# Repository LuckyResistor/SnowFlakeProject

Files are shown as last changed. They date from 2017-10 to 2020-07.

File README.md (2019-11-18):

# The Snowflake Decoration Project

This repository contains all hardware and software sources for the snowflake decoration project.
You will also find a number of documentation pages with the wiring or arrangement of the LEDs.

## More Information

Find more information about the project here:
[Snowflake Decoration Project](https://luckyresistor.me/projects/snow-flake-decoration/)

## License

All files are licensed under the GNU General Public License v3.0.

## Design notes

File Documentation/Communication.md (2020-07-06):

# Communication Protocol
## Summary
This document explains the details about the communication protocol and the idea behind this protocol as implemented in the firmware.

## Background and Idea
Each snow flake board has a data input and output pad to allow communication between multiple boards. The idea is that multiple snow flakes are chained to a single strand. On this strand, the snow flake boards use a communication protocol to synchronise the displayed effect.

1. A communication will make sure all snow flakes will display the same scene on the same strand. If all snow flakes display different scenes, it will look chaotic.
2. Because the internal oscillator of the MCU is used, not all snow flakes will display the scenes in exactly the same speed. A synchronisation signal will make sure there is no "shift" over time and all snow flakes will blend the scenes at the same time.
3. In an initial negotiation, each snow flake can find out the own position in the strand. This position can be used to create scenes which use all snow flakes in the same strand as one huge canvas. An effect could start at the first snow flake and run over all snow flakes in a smooth sequence.
4. Theoretically, the communication can also be used to detect how many snow flake boards are part of the same strand. This final number can be reported back the whole strand. It would keep the firmware flexible, boards can be added and removed from a strand and the scenes would always work with the current number of snow flakes. While this is possible, it is not part of the current firmware implementation. This firmware always assumes a fixed number of snow flakes, which is configured in the firmware as a configuration variable.

## Basic Principle
The communication is a primary/secondary system, where the first snow flake in the strand is the primary. The primary sends data down the strand which is received by the secondarys. Each secondary just passes the received data unmodified to the next secondary in the strand.

For robustness, the protocol uses a pulse length encoding. Different lengths of pulses encode bits and control information. Because of the variations in the CPU frequencies and unshielded cables, there is a certain timing tolerance built in the protocol.

## Negotiation
In the start process of each snow flake, the position and mode of the element is determined. First, the system checks if it is the first element in the strand:

1. The output line is set to high.
2. The system waits a short time if the input line goes to high.
3. In the case the input line goes to high, the system switches to secondary mode.
4. In the case the input line stays low, the system switches to primary mode.
5. The output line is set to low.

### Negotiation as Primary
The primary system assigns index zero to itself and sends the next index number (1) to the next secondary in the strand.

### Negotiation as Secondary
The secondary waits for an incoming number from the previous element in the strand. After it receives this number, it assigns this number to itself as index number and sends this number plus one to the next secondary in the strand.

### Index numbers
The index number is sent with the same protocol described below. The index number is encoded like this:

`0x1B7200XX` Where XX is the index number and all other digits in this number are used as "magic" to make sure this is a valid number.

### Error Handling
There are a number of error situations in the negotiation:

1. No number is received in a certain time frame, the negotiation times out.
2. The received number has the wrong format.

In this error cases, the snow flake will flag the error internally. The firmware will display a special scene to indicate the error to the user.

## Regular Communication
The regular communication consist of 32bit values sent from the primary to all secondarys. Currently there is a single command implemented:

Blend scene: `0xA514YYXX` - XX is the new scene number, YY the entropy value for the new scene.

This command is sent before all snow flakes shall blend to a new scene. A synchronisation signal is sent after this command, which will trigger the actual blend of the scene.

## Protocol
The protocol is using a simple pulse length encoding to transfer data. A pulse is pulling the data line to high and back to low. The time while the line was held high determines the meaning of this information element.

A timer is used to measure the incoming pules. Another timer is used to generate the outgoing pules. Both timer use the same clock source and divider to create the best possible precision.

- Length `0x0200`: Zero Bit
- Length `0x0400`: One Bit
- Length `0x0600`: Break Signal
- Length `0x0800`: Synchronisation Signal

For each transmission, a single 32bit value is sent. The lowest bit is sent first. A transmission consist of 32 zero or one bit signals, followed by a break signal.

A synchronisation signal can theoretically be sent at any time, but usually should be sent between value transmissions.

## Error handling

### Technical Problems
 
There are a number of technical situations how the transmission of signals and values can fail:

1. A signal with an unknown length is received.
2. A break signal is received, but the number of previously received zero and one bits is not 32.

In both cases, the communication is reset and the secondary is waiting for a new value. Any further handling of these problems make no sense, because there is no way to recover from them.

### Logical Problems

There are a number of logical problems which can occur. This logic problems are not handled by the firmware.

1. _There is inference in the transmission and wrong values are received._ For this case, a checksum would have to be added to the protocol. Also either a feedback channel would have to exist to report the problem and trigger resending the data - or the protocol would have to repeat each value a number of times to allow error correction.
2. _No data is received._ To catch this case, the firmware would have to run a kind of watch-dog timer. If no value is received in a given time, the board would have to signal this problem.

It makes no much sense to handle this logical problems. Most likely the reason is a hardware problem. The situation will be visible, because the strand will not synchronise the scenes or the elements will not start at all.

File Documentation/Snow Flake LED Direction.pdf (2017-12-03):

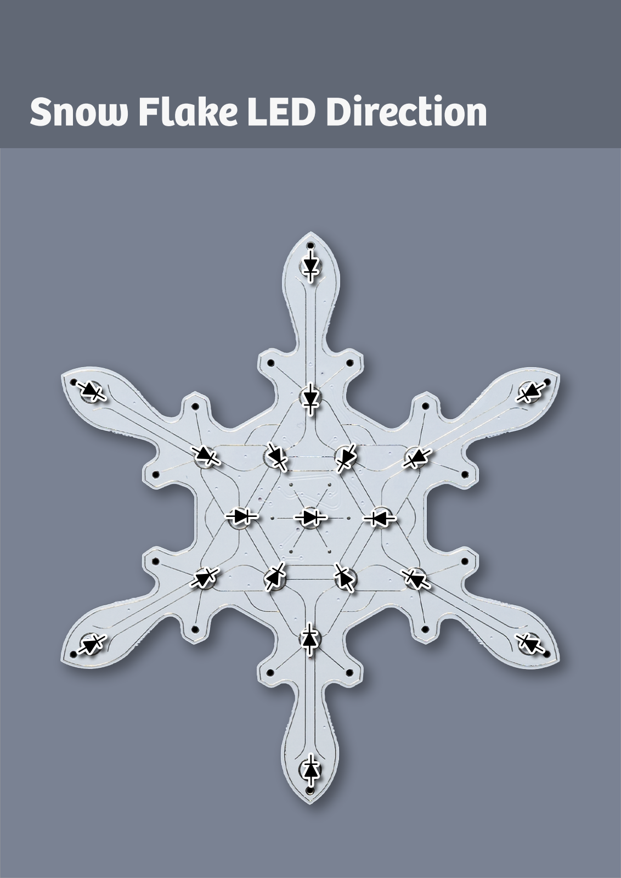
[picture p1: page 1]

Snow Flake LED Direction

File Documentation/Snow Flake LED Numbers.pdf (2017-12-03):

# Snow Flake LED Numbers

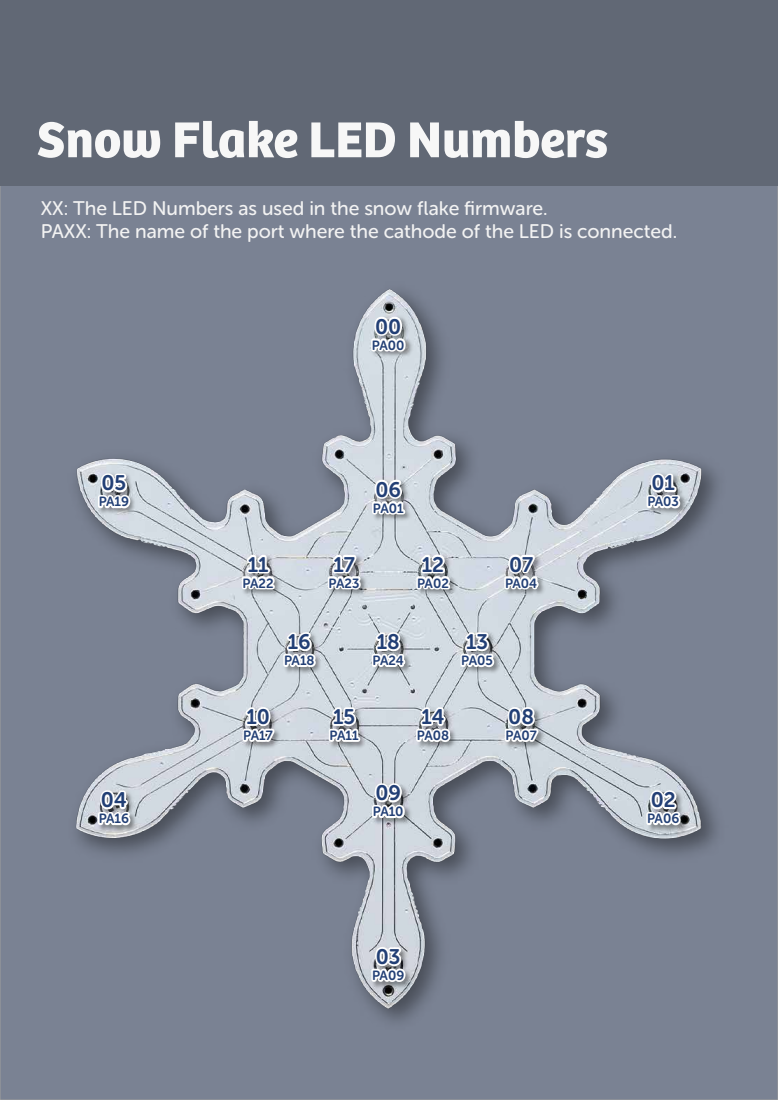
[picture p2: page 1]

XX: The LED Numbers as used in the snow flake firmware.
PAXX: The name of the port where the cathode of the LED is connected.

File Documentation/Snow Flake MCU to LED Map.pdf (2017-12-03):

# Snow Flake MCU to LED Map

This map shows which LED is connected to which pin on the MCU. The cathode of each LED is connected to the pin of the MCU, to test the LED connect the pin of the MCU to ground.

LEDX/RX is the reference from the electronic schema.
XX is the LED number as used in the firmware.
PAXX is the name/port of the MCU pin.

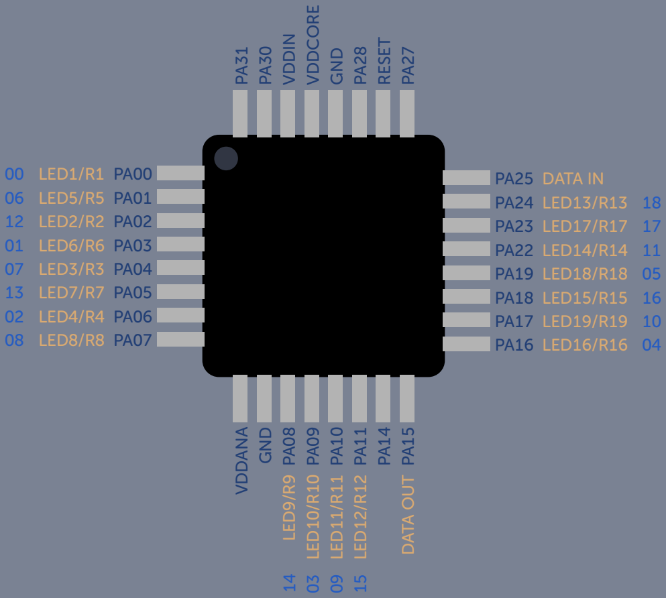
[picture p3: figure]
VDDANA; GND; VDDIN; VDDCORE; RESET; LED1/R1 LED5/R5 LED2/R2 LED6/R6 LED3/R3 LED7/R7 LED4/R4; LED8/R8; LED16/R16; LED19/R19; LED15/R15; LED18/R18; LED14/R14; LED17/R17; LED13/R13; DATA IN; LED9/R9; LED10/R10; LED11/R11; LED12/R12; DATA OUT

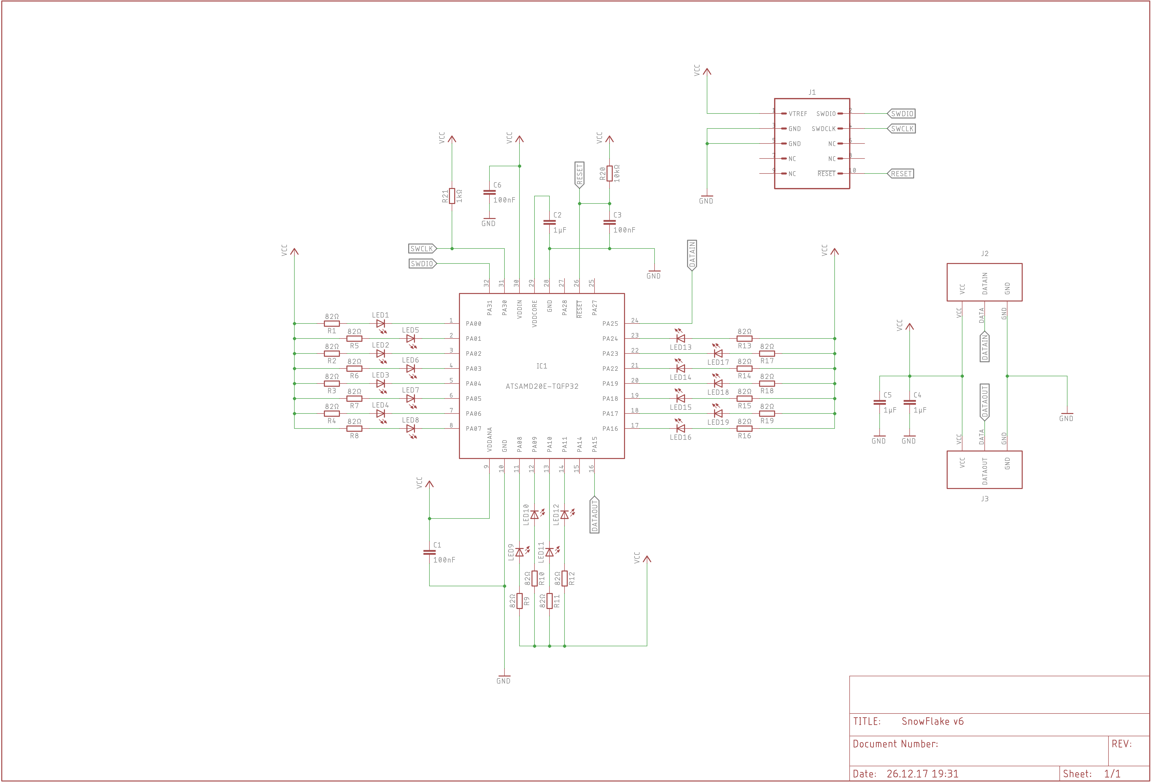
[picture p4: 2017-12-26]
Board/SnowFlake Schema.png

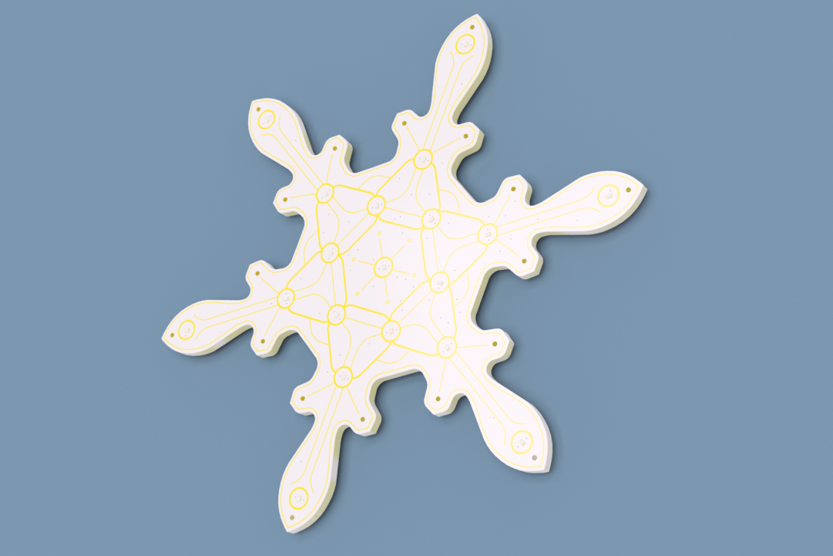
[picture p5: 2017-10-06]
Board/SnowFlake 3D Preview.png

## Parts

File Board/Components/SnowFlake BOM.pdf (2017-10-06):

### Snow Flake V5 BOM

Qty | Manufacturer | MPN | Schematic Reference | Description
1 | Harwin | M50-3600542R | J1 | 2x5 SMD Header for Programming
19 | Rohm | SCMP13WBC8W1 | LED1-19 | White 150mcd LED Package 0402
1 | Microchip | ATSAMD20E15A-AUT | IC1 | Atmel SAM D20E 32kb flash
19 | KOA Speer | RK73H2ATTD82R0F | R1-19 | 82Ω
1 | KOA Speer | RK73H2ATTDD1002F | R20 | 10kΩ
2 | Murata | GRM21BR60J106ME19L | C4,C5 | 10µF
3 | Murata | GRM21BR71H104JA01L | C1,C3,C6 | 0.1µF
1 | KOA Speer | RK73H2ATTDD1001F | R21 | 1kΩ
1 | Murata | GRM21BR71A105KA01L | C2 | 1µF

1

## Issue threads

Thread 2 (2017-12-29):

Pseudo random number generator is not seeded

LuckyResistor, 2017-12-29:
# Summary
The pseudo random number generator is not properly seeded at the start of the firmware. Therefore the master will cycle always through the exact same sequence of scenes.

# Background
It is not trivial to get good entropy from MCUs in a safe way. Just using the ADC to sample the voltage of a unconnected pin can work, but is not reliable. The Atmel SAM D20E can measure the internal temperature reference, which is hopefully a very noisy source. This would be worth a check.

# Implementation
All random numbers are generated using the methods in the `Helper` module. The original is the PRNG engine `gRandomGeneratorEngine` there. This engine has to be seeded with enough entropy from the hardware in the `initialize()` method. A call of the `seed()` function of the engine should be enough.

The hardware related methods to get the actual values have to be placed in the `Hardware` module so they can be accessed by the `Helper` module.

Closed 2017-12-30.

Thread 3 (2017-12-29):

Software Based Communication Too Unstable. Use Hardware Method Instead.

LuckyResistor, 2017-12-29:
# Summary
The current implementation to capture pulses from the data input is a very simple and fast implemented solution. It is not as reliable as it could be, which leads to communication problems, especially on long strands.

# Background
The PWM for the LEDs is done in software and requires a very precise interrupt. Every other interrupt requires to have a lower priority, otherwise e.g. the communication would lead to a visible flicker of the LEDs. This constraint makes it difficult to use interrupts for the communication in a precise way.

The original idea was to use a very slow pulse modulation to circumvent this issue. Mirroring the signal down the line turns out to be a problem. The small timing issues sum up and often the last elements in the strand can not interpret the pulses correctly.

# Possible Solutions
## Using Events and a Timer
The Atmel SAM D20E has a powerful event system. Sadly is is hard to understand and the documentation lacks examples. An event is nothing else as a configurable digital line inside of the MCU which can configured to connect some signal from a peripheral to the input of another peripheral.

Nevertheless it is possible to configure the external interrupt `EIC` to generate a event by configuring `CONFIGn` as `HIGH` level detector and let it generate a event. A timer can be connected to this signal. The timer can be configured in `PPW` mode to automatically capture the period and pulse-width from this signal. The interrupt to process the captured value can then be generated by the timer on capture instead of directly from the `EIC`.

## Serial Communication Using `SERCOM`
There is also the `SERCOM` system in the Atmel SAM D20E. When I designed the circuit I made sure the data in/out pins are also usable with the `SERCOM` module.

Configuring this module, it is possible to establish an asynchronous serial communication between the boards. The interrupt could be generated after receiving a single byte. If the BAUD rate is low enough, it should be no problem to capture every byte from the transmission in time.

This solution would require rewriting the communication from ground up to use a byte stream instead of fixed 32bit values. Also the synchronisation signal would be based on a sent byte and may not have the same precision as the simple signal currently used.

LuckyResistor, 2019-11-13:
The current implementation using a slow pulse width modulation captured via EIC has proven stable. Even on long strands, I observed no transmission errors.

Closed 2019-11-13.

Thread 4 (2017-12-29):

Scene Variations Depending on Strand Position

LuckyResistor, 2017-12-29:
# Summary
The main goal of the communication and strand position detection was to create scenes which play "over the whole strand". The current firmware lacks this kind of scenes and just synchronises the currently played scene to all other boards in the strand.

# Implementation
A board can access the current position of the own board and the number of boards in the strand. This will allow to e.g. shift an effect based on this information to play an animation over the whole strand.

One idea I have in mind is to run the sparkle effect in the `IceSparke` scene from top to bottom over all boards in sequence.

LuckyResistor, 2019-11-13:
Implemented in the Ice Sparke and Rain effect.

Closed 2019-11-13.

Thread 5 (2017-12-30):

If there is only one scene, the master still blends to the same one.

LuckyResistor, 2017-12-30:
# Summary
If there is only one scene defined, the master board still blends to the same scene. This can lead to glitches in the display of the scenes look very similar and do not use entropy.

# Solution
- Disable blending if only one scene is defined.
- Add a configuration option to enable blending on the same scene for entropy testing.

Closed 2017-12-30.

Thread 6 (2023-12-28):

Snowflakes turning off randomly

druck13, 2023-12-28:
After 3 or 4 years of working perfectly both of my sets of Pimoroni snowflakes have started turning themselves off after a period of anywhere from a few minutes to a couple of hours, sometimes just one set, but usually both sets within a few seconds of each others. They are powered from two different USB power supplies which work fine with Pi Zeros.

I looked at the configuration webpage to check I hadn't accidentally invoked some sort of auto switch off function using the button, but that doesn't seem to be the case.

Any ideas?

LuckyResistor, 2023-12-30:
Hello,

First of all, I apologize for my late response. I've encountered a similar issue with one decoration produced by Pimoroni, where some LEDs stayed on as if the microcontroller firmware suddenly stopped. In your case, do all the LEDs go black, or are some staying on?

From my experience, my own versions have been working flawlessly for several years. I don't believe this is a firmware issue; it seems more like a hardware problem. My guess, in order of likelihood, would be: a faulty capacitor, a faulty voltage regulator, hairline breaks in the flat band cables, oxidization on the connectors, or faulty solder joints. All of these could lead to lower voltage than expected, causing the microcontroller to stop.

If you have the necessary tools, I would be very interested in learning more. Could you please measure the voltage levels and check for any faulty capacitors? Also, I recommend raising this issue in the Pimoroni forums. It's probably the best place to get feedback from other users who may have encountered the same problem.

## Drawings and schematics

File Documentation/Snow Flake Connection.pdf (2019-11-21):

# Snow Flake Connection

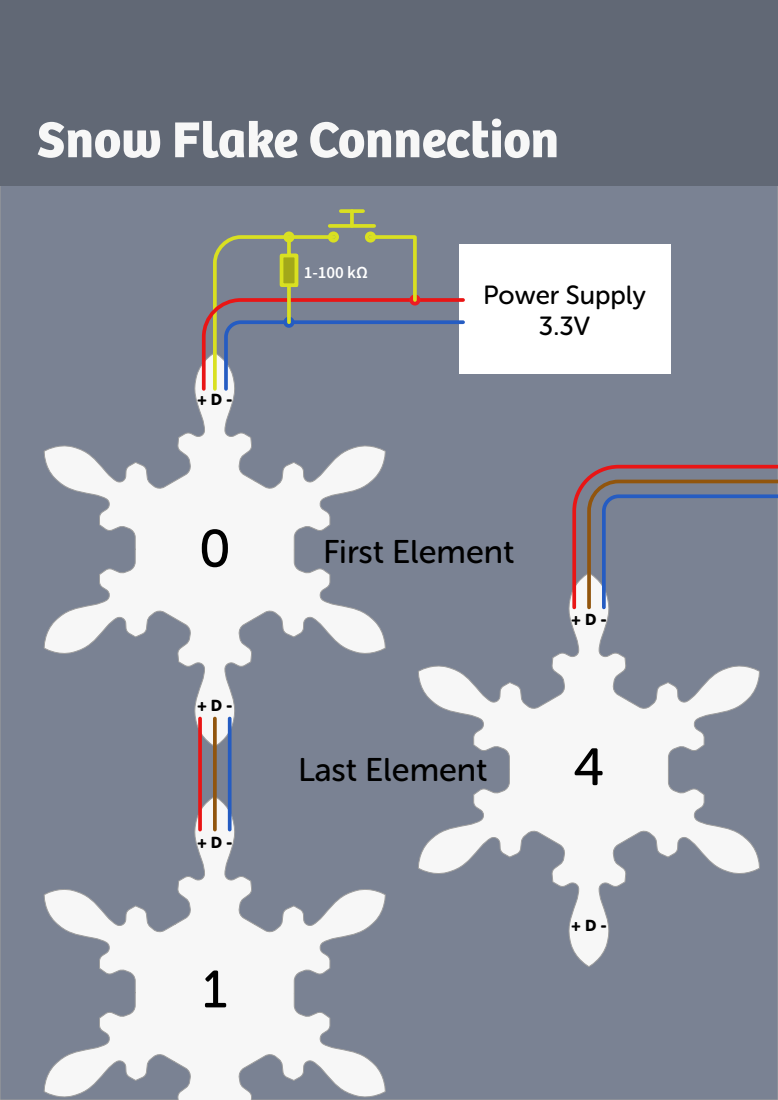
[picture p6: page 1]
Power Supply 3.3V; First Element; Last Element

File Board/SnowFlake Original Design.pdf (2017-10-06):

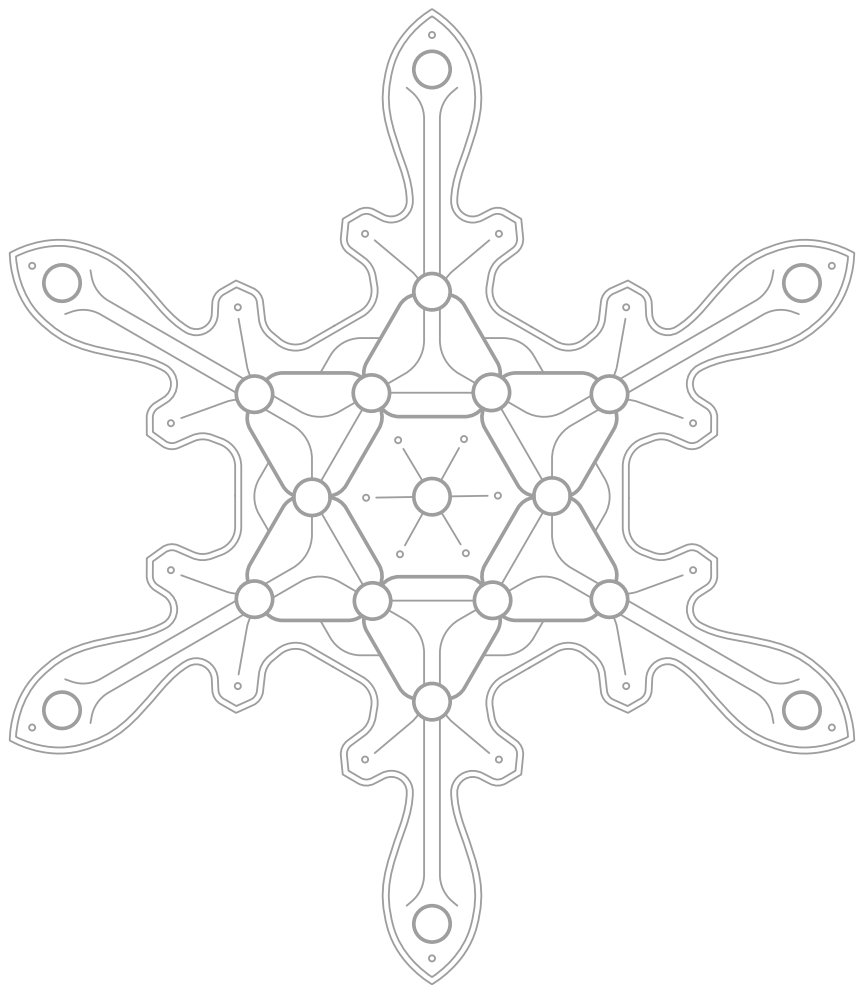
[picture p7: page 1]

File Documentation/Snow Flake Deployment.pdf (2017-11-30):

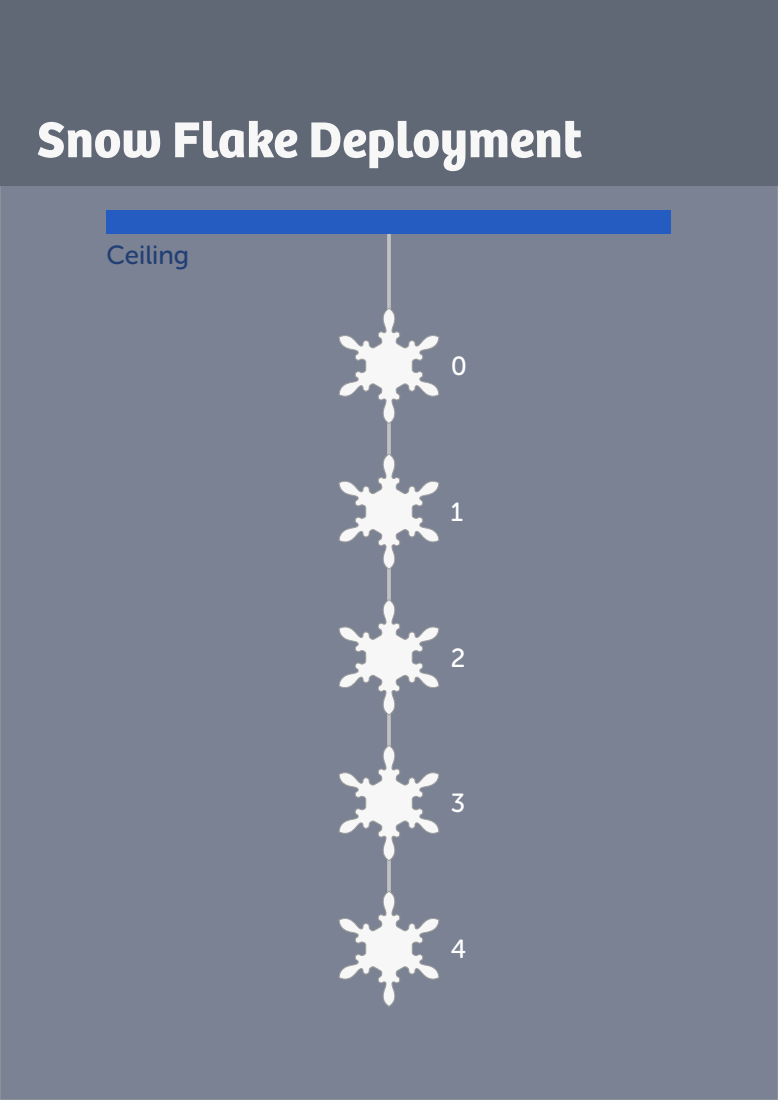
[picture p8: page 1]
Ceiling

Snow Flake Deployment

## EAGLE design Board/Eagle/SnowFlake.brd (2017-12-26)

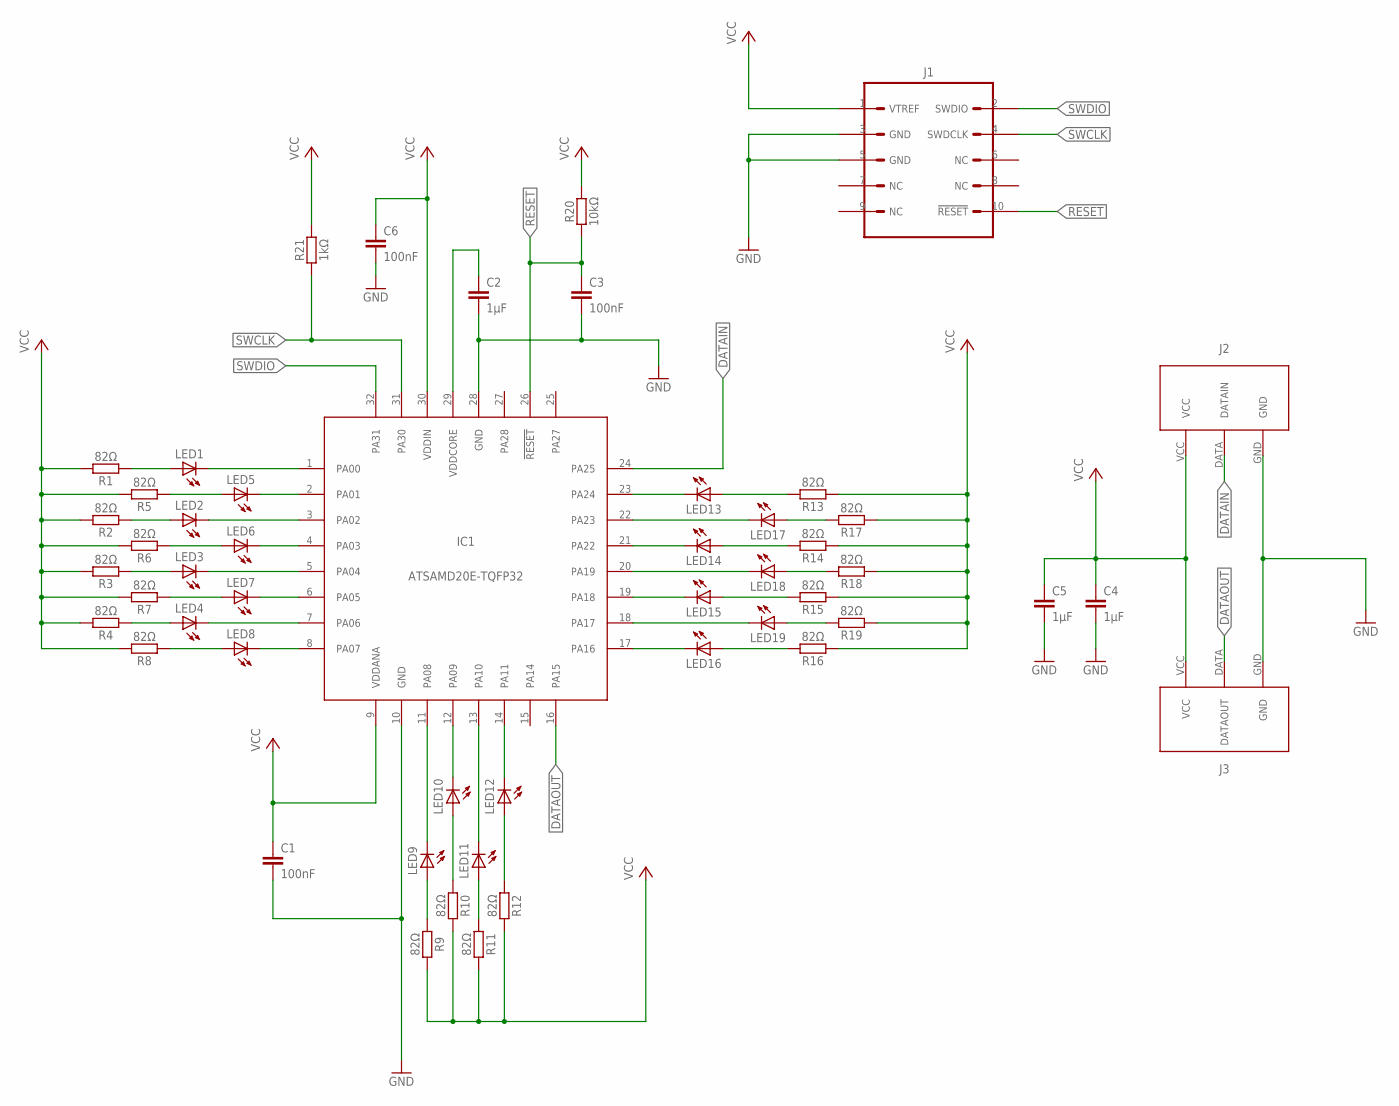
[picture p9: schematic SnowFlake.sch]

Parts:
C1, C3, C6: 100nF; CAPACITOR-0805-MURATA-GRM-21
C2, C4, C5: 1µF; CAPACITOR-0805-MURATA-GRM-21
IC1: ATSAMD20E-TQFP32; TQFP32-08
J1: CON-CORTEX-DEBUG-SMD1.27; CON-2X5-HARWIN-1.27
J2: CON-SNOWF-IN; CON-PADS-3XWIRE-B
J3: CON-SNOWF-OUT; CON-PADS-3XWIRE-T
LED1, LED2, LED3, LED4, LED5, LED6, LED7, LED8, LED9, LED10, LED11, LED12, LED13, LED14, LED15, LED16, LED17, LED18, LED19: LED0402; LED-0402-ROHM
R1, R2, R3, R4, R5, R6, R7, R8, R9, R10, R11, R12, R13, R14, R15, R16, R17, R18, R19: 82Ω; RESISTOR-0805-KOA-RK73-2A
R20: 10kΩ; RESISTOR-0805-KOA-RK73-2A
R21: 1kΩ; RESISTOR-0805-KOA-RK73-2A

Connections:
DATAIN: IC1.24 (PA25), J2.DATA (DATAIN)
DATAOUT: IC1.16 (PA15), J3.DATA (DATAOUT)
GND: C1.2, C2.2, C3.2, C4.2, C5.2, C6.2, IC1.10 (GND), IC1.28 (GND), J1.3 (GND), J1.5 (GND), J2.GND, J3.GND
LED1P: LED1.A, R1.1
LED1S: IC1.1 (PA00), LED1.C
LED2P: LED2.A, R2.1
LED2S: IC1.3 (PA02), LED2.C
LED3P: LED3.A, R3.1
LED3S: IC1.5 (PA04), LED3.C
LED4P: LED4.A, R4.1
LED4S: IC1.7 (PA06), LED4.C
LED5P: LED5.A, R5.1
LED5S: IC1.2 (PA01), LED5.C
LED6P: LED6.A, R6.1
LED6S: IC1.4 (PA03), LED6.C
LED7P: LED7.A, R7.1
LED7S: IC1.6 (PA05), LED7.C
LED8P: LED8.A, R8.1
LED8S: IC1.8 (PA07), LED8.C
LED9P: LED9.A, R9.1
LED9S: IC1.11 (PA08), LED9.C
LED10P: LED10.A, R10.1
LED10S: IC1.12 (PA09), LED10.C
LED11P: LED11.A, R11.1
LED11S: IC1.13 (PA10), LED11.C
LED12P: LED12.A, R12.1
LED12S: IC1.14 (PA11), LED12.C
LED13P: LED13.A, R13.2
LED13S: IC1.23 (PA24), LED13.C
LED14P: LED14.A, R14.2
LED14S: IC1.21 (PA22), LED14.C
LED15P: LED15.A, R15.2
LED15S: IC1.19 (PA18), LED15.C
LED16P: LED16.A, R16.2
LED16S: IC1.17 (PA16), LED16.C
LED17P: LED17.A, R17.2
LED17S: IC1.22 (PA23), LED17.C
LED18P: LED18.A, R18.2
LED18S: IC1.20 (PA19), LED18.C
LED19P: LED19.A, R19.2
LED19S: IC1.18 (PA17), LED19.C
RESET: C3.1, IC1.26 (!RESET), J1.10 (!RESET), R20.1
SWCLK: IC1.31 (PA30), J1.4 (SWDCLK), R21.1
SWDIO: IC1.32 (PA31), J1.2 (SWDIO)
VCC: C1.1, C4.1, C5.1, C6.1, IC1.9 (VDDANA), IC1.30 (VDDIN), J1.1 (VTREF), J2.VCC, J3.VCC, R1.2, R2.2, R3.2, R4.2, R5.2, R6.2, R7.2, R8.2, R9.2, R10.2, R11.2, R12.2, R13.1, R14.1, R15.1, R16.1, R17.1, R18.1, R19.1, R20.2, R21.2
VDDCORE: C2.1, IC1.29 (VDDCORE)

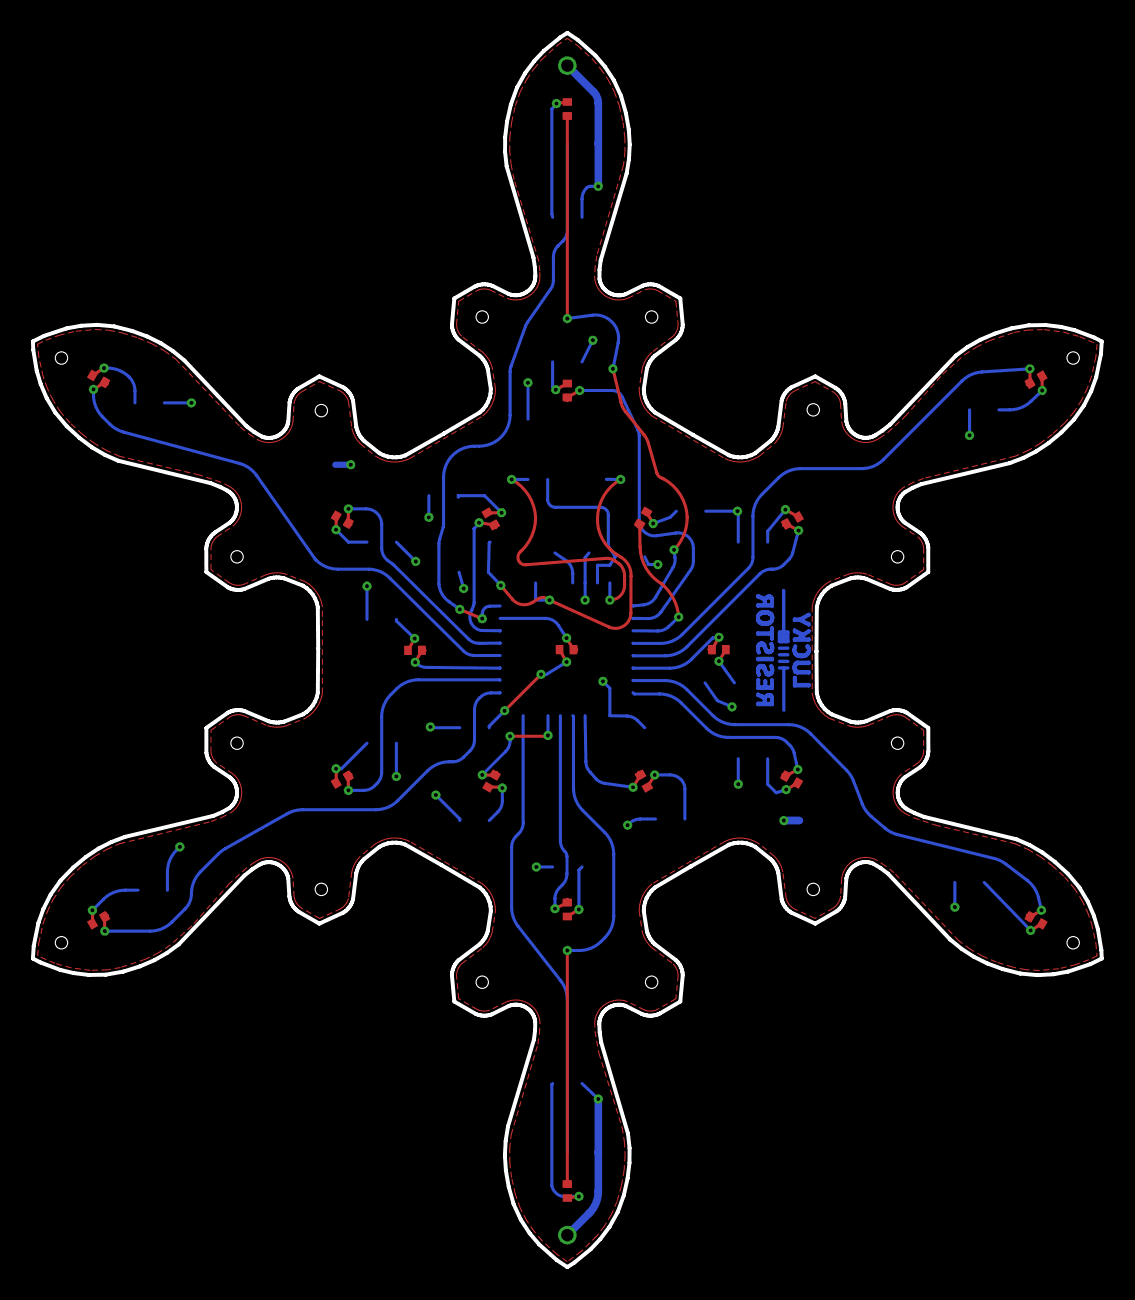
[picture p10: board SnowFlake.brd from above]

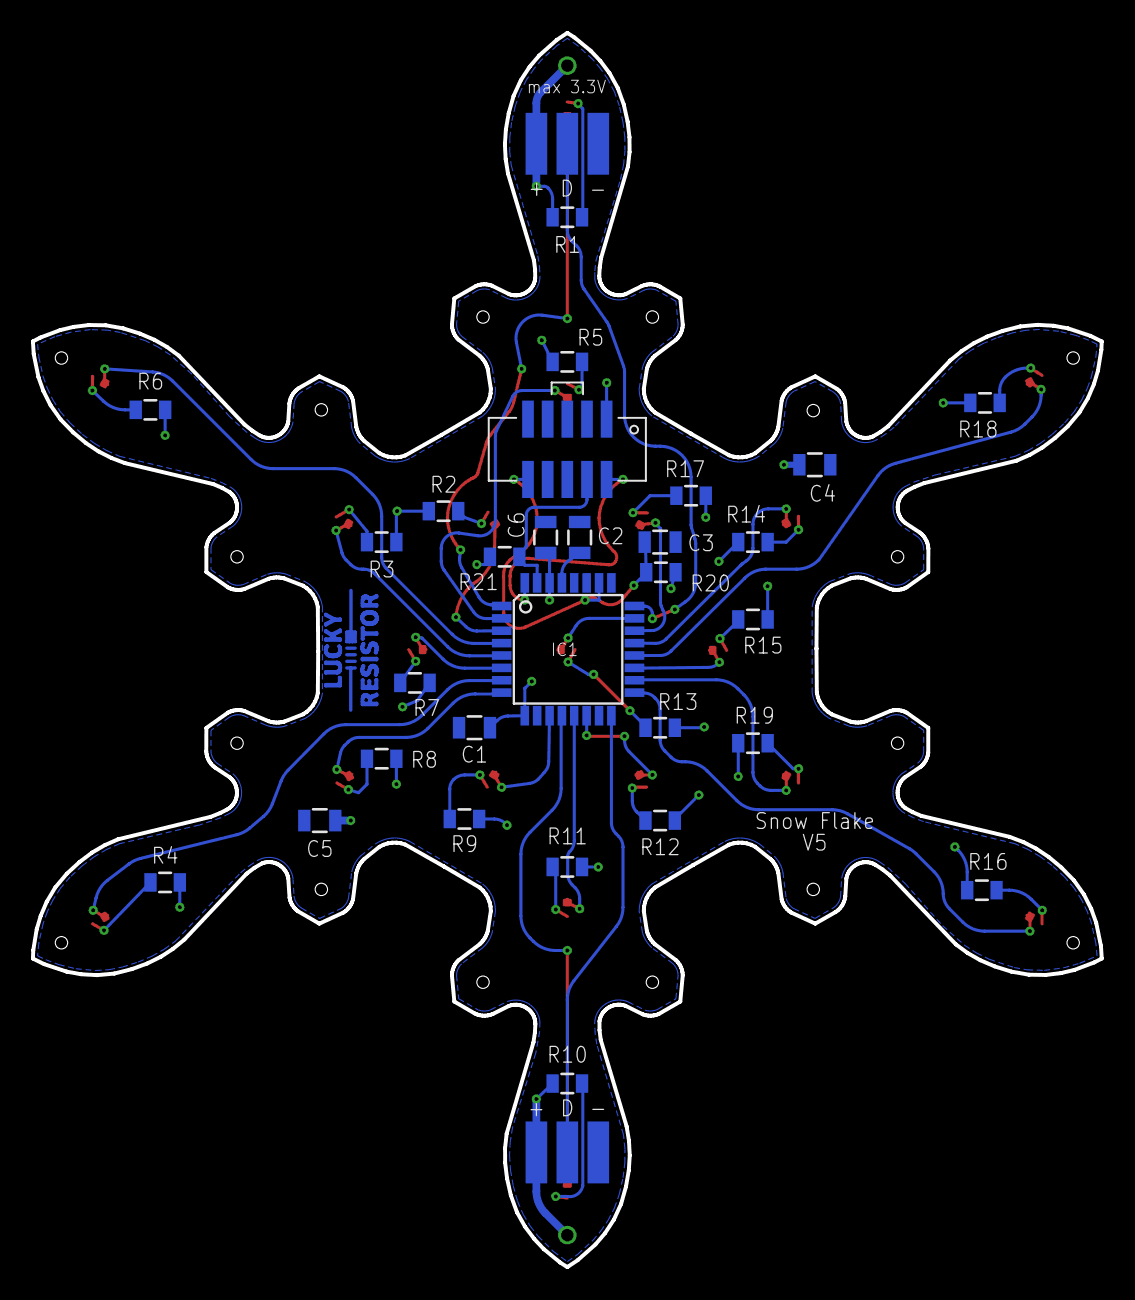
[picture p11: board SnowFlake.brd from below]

Board: 2 copper layers, 69.1 x 79.8 mm, 51 parts (32 on the bottom side), 46 nets.

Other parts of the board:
U$1: LR_LOGO_COPPER_8MM

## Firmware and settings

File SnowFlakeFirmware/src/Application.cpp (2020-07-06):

//
// Snow Flake Project
// ---------------------------------------------------------------------------
// (c)2017-2019 by Lucky Resistor. See LICENSE for details.
// https://luckyresistor.me
//
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
#include "Application.hpp"


#include "AutoScenes.hpp"
#include "Communication.hpp"
#include "Configuration.hpp"
#include "Display.hpp"
#include "ElapsedTimer.hpp"
#include "Hardware.hpp"
#include "Helper.hpp"
#include "SceneManager.hpp"
#include "Scene.hpp"
#include "Player.hpp"

#include "Chip.hpp"


namespace Application {
	
	
// Forward declarations.
void onDataReceived(uint32_t value);
void onSynchronization();
void onButtonPress(Communication::ButtonPress buttonPress);


/// The application mode
///
enum class Mode : uint8_t {
	Automatic, ///< Scenes are switched in regular intervals.
	Single, ///< One scene is displayed forever.	
};


/// The configuration mode.
///
enum class ConfigurationMode : uint8_t {
	Mode, ///< Configure the play mode.
	SceneDuration, ///< Configure the scene duration.	
};

	
/// The application state
///
enum class State : uint8_t {
	/// The current scene is playing.
	///
	Play,
	
	/// Primary sent the next scene index and waiting to send the synchronization.
	///
	SendSynchronization, 
	
	/// Blend the scene.
	///
	/// Primary is waiting for the synchronization finished to be sent which
	/// triggers the blend.
	///
	/// Secondary received the synchronization and starts the blend.
	///
	BlendScene,
	
	/// Request Off.
	///
	/// The used did a long press in on mode, an off state is requested.
	/// This state is only valid for the primary mode.
	///
	OffRequest,
		
	/// Off.
	///
	/// All LEDs are disabled. Secondaries are waiting for new scenes to wake up.
	///
	Off,
	
	/// Request On.
	///
	/// Turn the platform on if it was turned off.
	///
	OnRequest,
	
	/// Request Configuration.
	///
	/// The user requested configuration mode.
	/// This intermediate step allow to turn off all other flakes while configuring the strand. 
	///
	ConfigurationRequest,
	
	/// Configuration.
	///
	/// The configuration is displayed.
	///
	Configuration,
};
	


/// Duration of a scene blend in frames.
///
const uint32_t cBlendDuration = 80;

/// Duration how long a scene is shown in milliseconds.
///
const uint32_t cSceneDurations[] = {15000, 30000, 60000, 120000, 360000, 600000};

/// The number of scene durations.
///
const uint8_t cSceneDurationsCount = sizeof(cSceneDurations)/sizeof(uint32_t);

/// Duration how long the configuration is shown in milliseconds.
///
const uint32_t cConfigurationDuration = 6000; // 6s

/// Configuration LEDs A
///
const uint8_t cConfigurationRowA[] = { 6,  7,  8,  9, 10, 11};

/// Configuration LEDs B
///
const uint8_t cConfigurationRowB[] = {17, 12, 13, 14, 15, 16};


/// The mask for a command.
///
const uint32_t cCmdMask = 0xffff0000ul;

/// The mask for the "next scene" command.
///
const uint32_t cCmdNextScene = 0xa5140000ul;

/// The mask for the "off" command.
///
const uint32_t cCmdOff = 0xa5150000ul;

/// The mask for the scene name portion.
///
const uint32_t cCmdNextScene_SceneNameMask = 0x000000fful;

/// The mask for the scene entropy portion.
///
const uint32_t cCmdNextScene_EntropyMask = 0x0000ff00ul;


/// The index of the next scene to display.
///
volatile Scene::Name gNextSceneName = Scene::Black;

/// The entropy for the next scene to display.
///
volatile uint8_t gNextSceneEntropy = 0;


/// The state of the application.
///
volatile State gState = State::Play;

/// The elapsed timer to measure the length of a scene.
///
ElapsedTimer gSceneElapsedTime;

/// The application mode.
///
volatile Mode gMode = Mode::Automatic;

/// The selected scene duration.
///
volatile uint8_t gSceneDurationIndex = 2;

/// The current scene duration.
///
uint32_t gSceneDuration = (60000 - 50);

/// The automatic scenes index.
///
volatile uint8_t gAutoScenesIndex = 0;

/// The scene for the single mode.
///
volatile Scene::Name gSingleModeScene = Scene::IceSparkle;

/// The configuration mode.
///
volatile ConfigurationMode gConfigurationMode = ConfigurationMode::Mode;


/// Display an error state with the LEDs of the board.
///
__attribute__((noreturn))
void displayError(uint8_t errorCode)
{
	while (true) {
		Display::setLedLevel(errorCode, Display::cMaximumLevel);
		Display::synchronizeAndShow();
		Helper::delayMs(500);	
		Display::setLedLevel(errorCode, 0);
		Display::synchronizeAndShow();
		Helper::delayMs(500);
	}
}


/// Run a communication test.
///
/// This will send a new value every two seconds and display it as binary 
/// pattern on the snow flake.
///
void communicationTestPrimary()
{
	Helper::delayMs(2000);
	uint32_t value = 0;
	while (true) {
		for (uint8_t i = 0; i < Display::cLedCount; ++i) {
			const bool isBitSet = ((value&(1UL<<i)) != 0);
			Display::setLedLevel(i, (isBitSet ? Display::cMaximumLevel : 0));
		}
		Display::synchronizeAndShow();
		Communication::sendData(value);
		value += 1;
		Helper::delayMs(2000);
	}
}


/// Display the identifier of the board.
///
void displayBoardIdentifier()
{
	Display::setAllLedLevels(0);
	Display::setLedLevel(Communication::getIdentifier(), 32);
	for (uint8_t i = 0; i < 10; ++i) {
		Display::setLedLevel(Display::cLedCount-1, 16);
		Display::synchronizeAndShow();
		Helper::delayMs(100);
		Display::setLedLevel(Display::cLedCount-1, 0);
		Display::synchronizeAndShow();
		Helper::delayMs(100);
	}
}


/// Display the configuration.
///
void displayConfiguration()
{
	// Display the indicator for configuration.
	Display::setAllLedLevels(gConfigurationMode == ConfigurationMode::Mode ? 0 : 5);
	const bool indicatorState = (Helper::getSystemTimeMs() & (1u<<3u)) != 0;
	uint8_t indicatorLevel = (indicatorState ? 12 : 20);
	for (uint8_t i = 0; i < 6; ++i) {
		Display::setLedLevel(i, indicatorLevel);
	}
	
	// Light the middle LED for automatic mode
	if (gConfigurationMode == ConfigurationMode::Mode) {
		if (gMode == Mode::Automatic) {
			Display::setLedLevel(18, 20);
			Display::setLedLevel(cConfigurationRowA[gAutoScenesIndex], 40);
		} else if (gMode == Mode::Single) {
			auto sceneNumber = static_cast<uint8_t>(gSingleModeScene) - 1;
			auto rowB = sceneNumber / 6;
			auto rowA = sceneNumber % 6;
			Display::setLedLevel(cConfigurationRowA[rowA], 40);
			Display::setLedLevel(cConfigurationRowB[rowB], 15);
			Display::setLedLevel(cConfigurationRowB[(rowB+1)%6], 15);
		}		
	} else {
		for (uint8_t i = 0; i <= gSceneDurationIndex; ++i) {
			Display::setLedLevel(cConfigurationRowB[i], 40+i*2);
		}
	}
	
	Display::synchronizeAndShow();
}


/// Send an immediate scene change to all secondary boards.
///
void sendImmediateChange(Scene::Name nextSceneName, uint8_t nextSceneEntropy)
{
	Helper::delayMs(50);
	Communication::sendData(cCmdNextScene | static_cast<uint32_t>(nextSceneName) | (static_cast<uint32_t>(nextSceneEntropy) << 8));
	Communication::waitUntilReadyToSend();
	Helper::delayMs(50); // Wait until all boards are ready.
	Communication::sendSynchronization();
}


/// Set a random next scene for the current mode.
///
void setRandomNextScene()
{
	if (gMode == Mode::Automatic) {
		auto autoScenes = cAutoScenes[gAutoScenesIndex];
		auto scenes = autoScenes.scenes;
		auto scenesCount = autoScenes.count;
		gNextSceneName = scenes[Helper::getRandom8(0, scenesCount-1)];
	} else {
		gNextSceneName = gSingleModeScene;		
	}
	gNextSceneEntropy = Helper::getRandom8(0, 0xff);
}


/// The initialization for a board in primary mode.
///
void primaryInitialize()
{
	// Set the first scene to display.
	setRandomNextScene();
		
	// Send the scene number to all other boards.
	sendImmediateChange(gNextSceneName, gNextSceneEntropy);
			
	// Only for testing: Start with the user scene.
	if (cStartWithUserScene) {
		gMode = Mode::Single;
		gNextSceneName = Scene::User;
		gNextSceneEntropy = 0;
	}
			
	// Blend to the first scene from black.
	Player::displayScene(Scene::Black, 0);
	Player::blendToScene(gNextSceneName, gNextSceneEntropy, cBlendDuration);
	gSceneElapsedTime.start();
	while (Player::getState() == Player::State::Blend) {
		Player::animate();
	}
}


/// The initialization for a board in secondary mode.
///
void secondaryInitialize()
{
	Player::displayScene(Scene::Black, 0);
}


void initialize()
{
	// Initialize all modules.
	Hardware::initialize();
	Helper::initialize();
	Display::initialize();
	Communication::initialize();
	SceneManager::initialize();
	Player::initialize();

	// Wait for the negotiation in the communication between the elements.
	if (!Communication::waitForNegotiation()) {
		// If there was any error, go into error mode.
		displayError(static_cast<uint8_t>(Communication::getError()));
	}

	// Register the functions to receive data and the synchronization for boards in secondary mode.
	if (Communication::getIdentifier() != 0) {
		Communication::registerReadDataFunction(&onDataReceived);
		Communication::registerSynchronisationFunction(&onSynchronization);		
	}

	// If configured display the board identifier first.
	if (cTraceShowIdentifierOnStart) {
		displayBoardIdentifier();
	}	
	
	// Continue with the initialization based on the received identifier
	if (Communication::getIdentifier() == 0) {
		primaryInitialize();
	} else {
		secondaryInitialize();
	}
}


/// Process the off request state.
///
void processOffRequest()
{
	// Select the black scene and send this to all boards.
	gNextSceneName = Scene::Black;
	gNextSceneEntropy = 0;
	sendImmediateChange(gNextSceneName, gNextSceneEntropy);
	Player::blendToScene(gNextSceneName, gNextSceneEntropy, cBlendDuration);
	gState = State::Off;
}


/// Process the off state.
///
void processOff()
{
	// Wait here, until the user decides to turn the platform on.
}


/// Process the on request state.
///
void processOnRequest()
{
	// Set the first scene to display.
	setRandomNextScene();

	// Send the scene number to all other boards.
	sendImmediateChange(gNextSceneName, gNextSceneEntropy);
			
	// Set the scene duration.
	gSceneDuration = cSceneDurations[gSceneDurationIndex] - 50;
			
	// Blend to the first scene from black.
	Player::displayScene(Scene::Black, 0);
	Player::blendToScene(gNextSceneName, gNextSceneEntropy, cBlendDuration);
	gSceneElapsedTime.start();
	gState = State::BlendScene;
}


/// Process the play state.
///
void processPlay()
{
	if (gMode == Mode::Automatic && gSceneElapsedTime.elapsedTime() >= gSceneDuration) {
		// Select a random new scene, which is not the currently played one.
		auto lastScene = gNextSceneName;
		setRandomNextScene();
		while (lastScene == gNextSceneName) {
			setRandomNextScene();
		}
		Communication::sendData(cCmdNextScene | static_cast<uint32_t>(gNextSceneName) | (static_cast<uint32_t>(gNextSceneEntropy) << 8));
		gState = State::SendSynchronization;
	}
}


/// Process the send synchronization state.
///
void processSendSynchronization()
{
	if (gSceneElapsedTime.elapsedTime() >= gSceneDuration) {
		Communication::sendSynchronization();
		gState = State::BlendScene;
	}
}


/// Process the blend state.
///
void processBlendScene()
{
	if (Communication::isReadyToSend()) {
		Player::blendToScene(gNextSceneName, gNextSceneEntropy, cBlendDuration);
		gState = State::Play;
		gSceneElapsedTime.start();
	}
}


/// Process the configuration request.
///
void processConfigurationRequest()
{
	sendImmediateChange(Scene::Black, 0);
	gState = State::Configuration;
}


/// Process the configuration state.
///
void processConfiguration()
{
	if (gSceneElapsedTime.elapsedTime() >= cConfigurationDuration) {
		processOnRequest();
	}
}


/// The loop for a board in primary mode.
///
__attribute__((noreturn))
void primaryLoop()
{
	while (true) {
		// Handle the display.
		if (gState == State::Configuration) {
			// In configuration mode, display the current configuration parameter.
			displayConfiguration();
		} else {
			// Animate the current scene.
			Player::animate();			
		}
		// Handle the different states.
		switch (gState) {
			case State::Play: processPlay(); break;
			case State::SendSynchronization: processSendSynchronization(); break;
			case State::BlendScene: processBlendScene(); break;
			case State::OffRequest: processOffRequest(); break;
			case State::Off: processOff(); break;
			case State::OnRequest: processOnRequest(); break;
			case State::ConfigurationRequest: processConfigurationRequest(); break;
			case State::Configuration: processConfiguration(); break;
		}
		// Handle any button presses.
		const auto buttonPress = Communication::getNextButtonPress();
		if (buttonPress != Communication::ButtonPress::None) {
			onButtonPress(buttonPress);
		}
	}	
}


/// The function to receive data from the primary.
///
void onDataReceived(uint32_t value)
{
	// Check incoming commands.
	if ((value & cCmdMask) == cCmdNextScene) {
		gNextSceneName = static_cast<Scene::Name>(static_cast<uint8_t>(value & cCmdNextScene_SceneNameMask));
		gNextSceneEntropy = static_cast<uint8_t>((value & cCmdNextScene_EntropyMask) >> 8);
	} else if ((value & cCmdMask) == cCmdOff) {
		gNextSceneName = Scene::Black;
		gNextSceneEntropy = 0;
	}
}


/// The function to receive the synchronization from the primary.
///
void onSynchronization()
{
	gState = State::BlendScene;
}


/// The function to handle button presses for the different states.
///
void onButtonPress(Communication::ButtonPress buttonPress)
{
	if (buttonPress == Communication::ButtonPress::Long) {
		if (gState == State::Configuration) {
			if (gConfigurationMode == ConfigurationMode::Mode) {
				gConfigurationMode = ConfigurationMode::SceneDuration;
			} else {
				gConfigurationMode = ConfigurationMode::Mode;
			}
			gSceneElapsedTime.start();
		} else if (gState != State::Off && gState != State::OffRequest) {
			gState = State::OffRequest;	
		} else if (gState == State::Off) {
			gState = State::OnRequest;
		}
	} else if (buttonPress == Communication::ButtonPress::Short) {
		if (gState == State::Off) {
			gState = State::OnRequest;			
		} else if (gState == State::Play || gState == State::BlendScene || gState == State::SendSynchronization) {
			gState = State::ConfigurationRequest;
			gConfigurationMode = ConfigurationMode::Mode;
			gSceneElapsedTime.start();
		} else if (gState == State::Configuration) {
			if (gConfigurationMode == ConfigurationMode::Mode) {
				if (gMode == Mode::Automatic) {
					gAutoScenesIndex += 1;
					if (gAutoScenesIndex >= cAutoScenesCount) {
						gAutoScenesIndex = 0;
						gMode = Mode::Single;
						gSingleModeScene = static_cast<Scene::Name>(1);
					}
					} else if (gMode == Mode::Single) {
					gSingleModeScene = static_cast<Scene::Name>(static_cast<uint8_t>(gSingleModeScene) + 1);
					if (gSingleModeScene >= SceneManager::getSceneCount()) {
						gAutoScenesIndex = 0;
						gMode = Mode::Automatic;
						gSingleModeScene = static_cast<Scene::Name>(1);
					}
				}				
			} else {
				gSceneDurationIndex += 1;
				if (gSceneDurationIndex >= cSceneDurationsCount) {
					gSceneDurationIndex = 0;
				}
			}
			gSceneElapsedTime.start();
		}
	}
}


/// The loop for a board in secondary mode.
///
__attribute__((noreturn))
void secondaryLoop()
{
	while (true) {
		// Animate the current scene.
		Player::animate();
		// Act on application states
		if (gState == State::BlendScene) {
			Player::blendToScene(gNextSceneName, gNextSceneEntropy, cBlendDuration);
			gState = State::Play;			
		}
	}
}


void loop()
{
	if (Communication::getIdentifier() == 0) {
		primaryLoop();
	} else {
		secondaryLoop();
	}
}


}

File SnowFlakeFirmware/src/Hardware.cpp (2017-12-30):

//
// Snow Flake Project
// ---------------------------------------------------------------------------
// (c)2017 by Lucky Resistor. See LICENSE for details.
// https://luckyresistor.me
//
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
#include "Hardware.hpp"


#include "Configuration.hpp"
#include "Helper.hpp"

#include "Chip.hpp"


namespace Hardware {


/// The trace output masks for output A.
///
const uint32_t cTraceOutputAMasks[] = {0, 1<<15, 1<<27};
	
/// The trace output masks for output B.
///
const uint32_t cTraceOutputBMasks[] = {0, 1<<25, 1<<28};

/// The currently selected mask for trace output A.
///
const uint32_t cTraceOutputAMask = cTraceOutputAMasks[static_cast<uint8_t>(cTraceOutputPins)];

/// The currently selected mask for trace output B.
///
const uint32_t cTraceOutputBMask = cTraceOutputBMasks[static_cast<uint8_t>(cTraceOutputPins)];


/// Insert a short delay in the startup to have time to stop before things start.
///
void initializeDelayStart()
{
	// Avoid deadlock, wait some cycles.
	Helper::delayNop(20000);
}


/// Initialize all required clock sources for the CPU and the buses
///
void initializeCpuClocks()
{
	// Change the timing of the NVM access 
	NVMCTRL->CTRLB.bit.RWS = NVMCTRL_CTRLB_RWS_HALF_Val; // 1 wait state for operating at 2.7-3.3V at 48MHz.
	
	// Enable the bus clock for the clock system.
	PM->APBAMASK.bit.GCLK_ = true;

	// A) Initialize the DFLL to run in closed-loop mode at 48MHz
	// A0. Make a software reset of the clock system.
	GCLK->CTRL.bit.SWRST = true;
	while (GCLK->CTRL.bit.SWRST && GCLK->STATUS.bit.SYNCBUSY) {};
	// A1. Make sure the OCM8M keeps running.
	SYSCTRL->OSC8M.bit.ONDEMAND = 0;
	// A1. Set the division factor to 64, which reduces the 1MHz source to 15.625kHz
	GCLK->GENDIV.reg =
		GCLK_GENDIV_ID(3) | // Select generator 3
		GCLK_GENDIV_DIV(64); // Set the division factor to 64
	// A2. Create generic clock generator 3 for the 15KHz signal of the DFLL
	GCLK->GENCTRL.reg =
		GCLK_GENCTRL_ID(3) | // Select generator 3
		GCLK_GENCTRL_SRC_OSC8M | // Select source OSC8M
		GCLK_GENCTRL_GENEN; // Enable this generic clock generator
	while (GCLK->STATUS.bit.SYNCBUSY) {}; // Wait for synchronization
	// A3. Configure DFLL with the
	GCLK->CLKCTRL.reg =
		GCLK_CLKCTRL_ID_DFLL48M | // Target is DFLL48M
		GCLK_CLKCTRL_GEN(3) | // Select generator 3 as source.
		GCLK_CLKCTRL_CLKEN; // Enable the DFLL48M
	while (GCLK->STATUS.bit.SYNCBUSY) {}; // Wait for synchronization
	// A4. Bug workaround, everything is locked if on demand isn't disabled at this point.
	SYSCTRL->DFLLCTRL.bit.ONDEMAND = false;
	while (!SYSCTRL->PCLKSR.bit.DFLLRDY) {}; // Wait for synchronization.
	// A5. Change the multiplication factor.	
	SYSCTRL->DFLLMUL.bit.MUL = 3072; // 48MHz / (1MHz / 64)
	SYSCTRL->DFLLMUL.bit.CSTEP = 1; // Coarse step = 1
	SYSCTRL->DFLLMUL.bit.FSTEP = 1; // Fine step = 1
	while (!SYSCTRL->PCLKSR.bit.DFLLRDY) {}; // Wait for synchronization.
	// A6. Start closed-loop mode
	SYSCTRL->DFLLCTRL.reg |=
		SYSCTRL_DFLLCTRL_MODE | // 1 = Closed loop mode.
		SYSCTRL_DFLLCTRL_QLDIS; // 1 = Disable quick lock.
	while (!SYSCTRL->PCLKSR.bit.DFLLRDY) {}; // Wait for synchronization.
	// A7. Clear the lock flags.
	SYSCTRL->INTFLAG.bit.DFLLLCKC = 1;
	SYSCTRL->INTFLAG.bit.DFLLLCKF = 1;
	SYSCTRL->INTFLAG.bit.DFLLRDY = 1;
	// A8. Enable the DFLL
	SYSCTRL->DFLLCTRL.bit.ENABLE = true;
	while (!SYSCTRL->PCLKSR.bit.DFLLRDY) {}; // Wait for synchronization.
	// A9. Wait for the fine and coarse locks.
	while (!(SYSCTRL->INTFLAG.bit.DFLLLCKC && SYSCTRL->INTFLAG.bit.DFLLLCKF)) {};
	// A10. Wait until the DFLL is ready.
	while (!SYSCTRL->INTFLAG.bit.DFLLRDY) {};
}


/// Switch the CPU speed to the 48MHz clock.
///
void initializeCpuSpeed()
{	
	// Set the divisor of generic clock 0 to 0
	GCLK->GENDIV.reg =
		GCLK_GENDIV_ID(0) | // Select generator 0
		GCLK_GENDIV_DIV(0);
	while (GCLK->STATUS.bit.SYNCBUSY) {}; // Wait for synchronization		
	// Switch generic clock 0 to the DFLL
	GCLK->GENCTRL.reg =
		GCLK_GENCTRL_ID(0) | // Select generator 0
		GCLK_GENCTRL_SRC_DFLL48M | // Select source DFLL
		GCLK_GENCTRL_IDC | // Set improved duty cycle 50/50
		GCLK_GENCTRL_GENEN; // Enable this generic clock generator
	while (GCLK->STATUS.bit.SYNCBUSY) {}; // Wait for synchronization
}
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

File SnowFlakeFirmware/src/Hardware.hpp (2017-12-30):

//
// Snow Flake Project
// ---------------------------------------------------------------------------
// (c)2017 by Lucky Resistor. See LICENSE for details.
// https://luckyresistor.me
//
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
#pragma once


#include <cstdint>


/// The hardware abstraction layer.
///
namespace Hardware {


/// The port.
///
enum class PortName : uint8_t {
	PA00 = 0,
	PA01 = 1,
	PA02 = 2,
	PA03 = 3,
	PA04 = 4,
	PA05 = 5,
	PA06 = 6,
	PA07 = 7,
	PA08 = 8,
	PA09 = 9,
	PA10 = 10,
	PA11 = 11,
	PA14 = 14,
	PA15 = 15,
	PA16 = 16,
	PA17 = 17,
	PA18 = 18,
	PA19 = 19,
	PA22 = 22,
	PA23 = 23,
	PA24 = 24,
	PA25 = 25,
	PA27 = 27,
	PA28 = 28,
	PA30 = 30,
	PA31 = 31,
};


/// The multiplexing function.
///
enum class Multiplexing : uint8_t {
	Off, ///< Do not connect to any peripheral.
	A, ///< Connect to external interrupt.
	B, ///< Connect to analog input (REF, ADC, AC, PTC, DAC).
	C, ///< Connect to SERCOM.
	D, ///< Connect to SERCOM-ALT.
	E, ///< Connect to timer (TC).
	G, ///< Connect to COM.
	H, ///< Connect to Generic Clock.
};

/// Port Configuration.
///
enum class PortConfiguration : uint8_t {
	Disabled, ///< Remove the port from the GPIO (Hi-Z)
	Output, ///< Configure the port as output.
	Input, ///< Configure the port as input.
};

/// Pull up/down.
///
enum class PortPull : uint8_t {
	None, ///< Use no pull up/down resistor.
	Up, ///< Connect a pull up resistor.
	Down ///< Connect a pull down resistor.
};

/// The port state.
///
enum class PortState : uint8_t {
	Low, ///< Set the port to high state.
	High ///< Set the port to low state.
};


/// Initialize the MCU hardware.
///
void initialize();	


/// Set the basic port configuration.
///
void setPortConfiguration(PortName port, PortConfiguration configuration, PortPull pull = PortPull::None);

/// Set the peripheral multiplexing function for a pin.
///
void setPeripheralMultiplexing(PortName port, Multiplexing muxFunction);

/// Get the mask for a port.
///
constexpr uint32_t getMaskForPort(PortName port) {
	return (1UL << static_cast<uint8_t>(port));
}

/// Set the output for a port configured as output.
///
void setOutput(PortName port, PortState output);

/// Get the input state from a port configured as input.
///
PortState getInput(PortName port);

/// Get entropy for the pseudo random number generator
///
uint32_t getEntropy();

/// Set trace output A to high state.
///
void setTraceOutputA();

/// Set trace output A to low state.
///
void clearTraceOutputA();

/// Toggle trace output A.
///
void toggleTraceOutputA();

/// Set trace output B to high state.
///
void setTraceOutputB();

/// Set trace output B to low state.
///
void clearTraceOutputB();

/// Toggle trace output B
///
void toggleTraceOutputB();

	
}

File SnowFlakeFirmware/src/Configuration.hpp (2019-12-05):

//
// Snow Flake Project
// ---------------------------------------------------------------------------
// (c)2017-2019 by Lucky Resistor. See LICENSE for details.
// https://luckyresistor.me
//
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
#pragma once


/// The configuration for trace outputs.
///
enum class TraceOutputPins : uint8_t {
	Disabled = 0, ///< The trace output is disabled.
	DataLines = 1, ///< The trace output is routed to the data-in and data-out lines.
	PA27_28 = 2 ///< The trace output is routed to the PA27 and PA28 pins (pin 25 + 27).
};

/// The source for the output signals.
///
enum class TraceOutputSource : uint8_t {
	
	/// The trace output is disabled.
	///
	Disabled, 
	
	/// Output A is set to high while a new frame is calculated.
	/// Output B is set to high at the frame synchronization.
	///
	FrameClaculationTime,
	
	/// Output A is set high while the display interrupt is running.
	/// Output B is set high for the interrupt of PWM counter 0.
	///
	DisplayInterruptTime,
};


/// The number of elements in the strand.
///
const uint8_t cConfigurationStrandElementCount = 5;

/// Start with the user scene for testing.
///
const bool cStartWithUserScene = false; // false for production


/// Should the start be delayed?
///
const bool cTraceStartDelayed = false; // false for production.

/// Use a very long negotiation duration.
///
/// This is used if you have attached a programmer to the chip which delays the
/// start up to one second.
///
const bool cTraceLongNegotiation = true; // false for production.

/// Display the identifier for two seconds after initialization.
///
/// If you enable this, each snow flake will briefly show the identifier after
/// the negotiation. The identifier is displayed by lighting up the LED with the
/// identifier number and the center LED.
///
const bool cTraceShowIdentifierOnStart = true; // false for production.

/// The configuration for the trace outputs pins.
///
const TraceOutputPins cTraceOutputPins = TraceOutputPins::Disabled; // Disabled for production.

/// The configuration for the trace output source.
///
const TraceOutputSource cTraceOutputSource = TraceOutputSource::Disabled; // Disabled for production.

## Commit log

2017-10-04 Working on the clock setup and adding access to the LED pins.
2017-10-04 Create an interrupt from TC0.
2017-10-05 First simple HAL layer with working LED PWM display and delay function.
2017-10-06 Adding boards, design and BOM to the project.
    Add missing gerber files for the bottom layer.
    [SnowFlake BOM.csv, SnowFlake.brd, SnowFlake.sch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]
2017-10-09 Implemented initial scene management.
    - Renamed all header files with the suffix "hpp" to get the correct syntax highlighting in Atmel studio.
    - Changed linker option to use a size optimized library.
    [Application.cpp, Display.cpp]
2017-10-18 Adding the Player class.
    - Adding a "chip.h" header to make switching the MCU simple for non studio builds.
    - Change the scene registry to allow storing in flash memory.
    - Prepare the ice sparkle scene (not implemented yet).
2017-10-21 Adding a fixed point data type for fast calculations.
    - Adding the new data type Fixed16 for very fast integer fixed point calculations.
    - Adding trace output configuration for timing measurements.
    - Converting the PixelMath functions into the new PixelValue data type.
    [Configuration.hpp, Display.cpp]
2017-10-22 New random particle scene and display PWM code optimization.
    - Added a not yet finished random particle scene.
    - Optimized the display code to improve the very low LED levels. Make a smooth transition to off there.
2017-10-24 Fixing the initial state of the display after first optimization.
    [Display.cpp]
2017-10-24 Fixing the wait cycle to correctly wait for corase and fine tuning before switching to the new clock.
    [Hardware.cpp]
2017-10-24 Correcting the random counter class to get the particle effect working.
    [RandomFrameCounters.hpp]
2017-10-24 Optimizing display performance by precalculating the PWM masks for all LEDs.
    - Optimizing the black to white transition with better timing.
2017-11-15 Working on the random scene transitions and other small improvements.
    - Adding a new simple diagonal scene.
    - Moving the used LED maps into a separate file to share them between scenes.
    - Add 8bit random numbers.
    - Add functions to get "hard" (no blend) and "smooth" (with blend) numbers from the array.
    - Fixing constants of the display module to optimize compilation.
    - Adding a (currently not working) random transition between scenes.
    [Application.cpp, Display.cpp, IceSparkle.cpp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]
2017-11-15 Avoid infinite loop when repeated scene chosen
    [Application.cpp]
2017-11-26 Create a final version of the "ice sparkle" scene.
    - Adding an offset to the RandomFrameCounters class to allow multiple instances with the same scene data block.
    - Create a module with shared value arrays.
    - Increase the index for the interpolating array to 16bit for larger arrays.
    - Adding the "ice sparkle" scene to the scene rotation.
    - Adding functions to the Frame class to multiple and add frames.
2017-11-27 Adding new scene "Sky with Stars".
    - Fixing the project file for release builds.
    - Fix a minor problem in the IceSparke scene.
    [Application.cpp, IceSparkle.cpp]
2017-11-30 Adding simple document about the idea of the deployment and how to connect the boards.
2017-12-03 Working on the communication component. Implementing the data send functionality and initial negotiaton.
    - Adding configuration functions to the HAL to configure ports in a visual way (slow but readable code).
    - Configure the timer and interrupt system to send the 32bit values and synchronization.
2017-12-09 Created a first working communication between the boards.
    - Refactored the code into more functions to make it readable.
    - Added a elapsed timer class to measure timeouts.
    - Added more global configuration options.
2017-12-26 Fixing the capacitor value in the schema from 10µF to 1µF.
    [SnowFlake.brd, SnowFlake.sch]
2017-12-27 Adding the new scene "waves" to the firmware.
    - Adding entropy to the scenes and communicate it to other boards.
    - Adding a shifting map template class for shifting map calculations.
    - Fixing minor code issues with the `FrameIndex` type.
    - Removing the `Simple...` example scenes from the scene display for the production version.
    - Adding a map with rotation LED index mappings.
    - Adding new firmware binaries for this release.
    [Application.cpp, IceSparkle.cpp, LedMaps.cpp]
2017-12-30 Fixes #5: Disable blending on the same scene if not wanted.
    [Application.cpp, Configuration.hpp]
2017-12-30 Resolves #2: Reading some noisy values from the internal temperature sensor to generate a seed value for the PRNG.
    [Hardware.cpp, Hardware.hpp]
2019-11-11 Add configuration and on/off via push button on the first data line.
2019-11-12 Adding a new scene "rain" to the firmware.
    - Fixing the duration values.
    - Adding a 4. auto program like the 1. with the additional rain scene.
    [Application.cpp, LedMaps.cpp]
2019-11-17 Removing race conditions in user input button handling.
    - Fix: Remove race condition by introducing a synchronized queue.
    - Cleanup: Moving the auto scene arrays into an own module to keep the application logic small.
    [Application.cpp]
2019-11-21 Adding the push button to the connection diagram.

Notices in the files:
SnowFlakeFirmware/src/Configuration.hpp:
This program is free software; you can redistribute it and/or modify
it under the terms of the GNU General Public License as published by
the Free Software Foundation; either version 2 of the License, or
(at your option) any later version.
